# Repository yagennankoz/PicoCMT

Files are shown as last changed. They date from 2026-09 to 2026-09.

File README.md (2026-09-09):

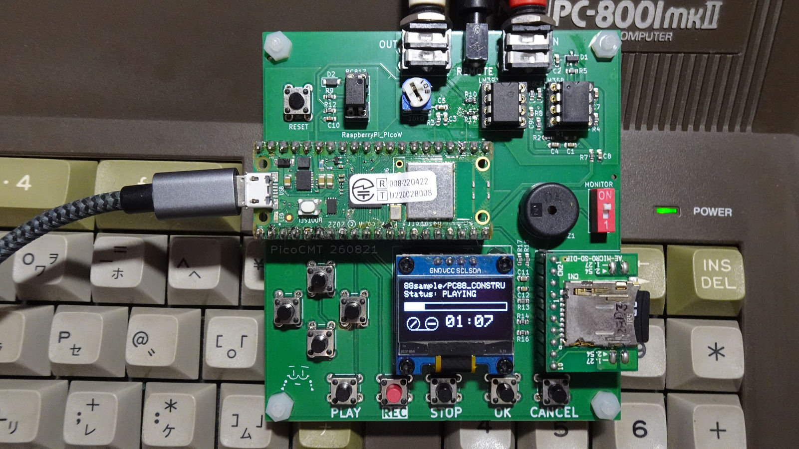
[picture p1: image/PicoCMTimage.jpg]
PicoCMT


# PicoCmt - 8bit PC用 CMT(カセット磁気テープ) エミュレータ

Raspberry Pi Pico W を使用した、8bitレトロPC向けのカセット磁気テープ（CMT）エミュレータです。
SDカードに保存されたテープイメージファイル（`.T88`, `.CMT`, `.CAS`）を実機へ音声信号としてロードしたり、実機からのセーブ音声を録音してデジタルファイルに変換・保存することができます。

## 主な機能
* **ファイルからの再生 (LOAD)**
  * 対応フォーマット: `.T88`, `.CMT`, `.CAS`)
  * ファイル内のデータをFSK音声信号に変換し、PCへ出力します。
  * 無音区間（ブランク）のスキップや頭出しシークが可能です。(T88)
* **実機からの録音・変換 (SAVE)**
  * PCからの出力音声を録音し、自動的にデジタル形式（`.T88`, `.CMT`, `.CAS`）に変換してSDカードに保存します。
  * 新規録音だけでなく、既存ファイルへの追記録音（アペンド）にも対応しています。
* **Wi-Fi / FTPサーバー機能**
  * Pico W のWi-Fi機能を利用し、内蔵のFTPサーバーを起動できます。
  * SDカードを抜き差しすることなく、PCやスマホからネットワーク経由でファイルの追加・削除が可能です。
  * 設定したWi-Fiパスワード等は独自の暗号化処理を経てEEPROMに安全に保存されます。

---

## 必要なハードウェア

基板のガーバーデータは`hardware/JLCPCB`を参照してください。JLCPCB等に発注することでプリント基板の生産が可能です。
主要な部品構成は以下の通りです。詳細な部品リストや定数は `hardware/parts.md` を参照してください。

* **マイコンボード:** Raspberry Pi Pico W
* **ディスプレイ:** 0.96インチ OLEDディスプレイ (SSD1306 / I2C接続)
* **ストレージ:** MicroSDカードモジュール (SPI接続)
* **アナログ回路:** 
  * オペアンプ `MCP6022` (信号増幅・波形整形用)
  * コンパレータ `LM393` (録音パルス検出用)
  * フォトカプラ `PC817` (REMOTE端子制御用)
* **インターフェース:**
  * タクトスイッチ ×10 (操作用)
  * 3.5mm モノラルジャック ×2 (LOAD用, SAVE用)
  * 2.5mm モノラルジャック ×1 (REMOTE制御用)
  * 圧電ブザー (モニタースピーカー用)

---

## 開発環境とビルド手順

本プロジェクトは **PlatformIO** を使用して開発されています。Arduinoコアには `earlephilhower` 版の Raspberry Pi PicoW/RP2040 コアを使用します。

### 1. インストール
1. リリースに配置されているファームウェアファイル`PicoCMT*.uf2`をダウンロードします。
2. PCとRaspberryPi PicoWをUSB接続します。
3. RaspberryPi PicoWの`BOOTSEL`ボタンを押しながら、PicoCMT基板上のRESETボタンを押下します。
4. PC上でRaspberryPi PicoWのフォルダが開かれますので、そこに`PicoCMT*.uf2'をコピーします。
5. RaspberryPi PicoWが自動で再起動され、PicoCMTが起動します。

### 2. 開発環境の準備
以下はソースコードからビルドする際の手順です。通常は不要です。
1. [Visual Studio Code (VSCode)](https://code.visualstudio.com/) をインストールします。
2. VSCodeの拡張機能から **PlatformIO IDE** をインストールします。
3. リポジトリをクローンしてください。

### 3. PIOファイルのコンパイルについて
PicoのPIO（アセンブリ）コードは、ビルド前に自動的にC/C++のヘッダファイルに変換される仕組みになっています。
`platformio.ini` 内の `extra_scripts = pre:scripts/generate_pio_headers.py` により、ビルド時に自動で `pio/` フォルダ内のファイルが処理され、`include/generated/` ディレクトリにヘッダファイルが出力されます。手動で実行する必要はありません。

### 4. ビルド
1. VSCodeで `PicoCmt` フォルダを開きます。
2. 初回起動時、PlatformIOが自動的に必要なツールチェーンとライブラリ（Adafruit GFX, SSD1306等）をダウンロードします。
3. 画面下のPlatformIOツールバーから **[✓] Build** をクリックしてビルドを実行します。

---

## 使い方・操作方法

操作方法については、付属の **操作マニュアル** を参照してください。
基本的なUI操作、再生（LOAD）・録音（SAVE）の手順、ボーレートの変更方法、Wi-Fi/FTP設定方法について記載されています。

---

## 注意事項・免責事項

* 本デバイスの接続や使用により発生したいかなる損害（レトロPC本体の故障、データの消失など）についても、開発者は責任を負いません。自己責任でご使用ください。
* Wi-Fi設定を保存する際に入力する「4桁のPINコード」は、設定情報を復号するために必要です。忘れるとWi-Fiに接続できなくなり、設定の初期化（クリア）が必要になります。

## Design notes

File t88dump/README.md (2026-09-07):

# T88/CMT フォーマット アナライザー & バイナリダンプ

PC-8801などのレトロPCで利用されるカセットテープイメージファイル（`.t88` および `.cmt`）の構造解析と、バイナリダンプを行うためのGUIツールです。
Pythonの標準ライブラリ（Tkinter）のみで実装されており、外部依存パッケージなしで軽量に動作します。

## ✨ 主な機能 (Features)

- **T88フォーマットの構造解析**
  - T88ファイル内の構造タグ（Blank, Data, Space, Mark 等）をパースし、Treeviewで一覧表示。
  - 再生時間（Ticks / ミリ秒）やデータサイズ、ボーレート（600/1200bps）を自動計算して表示。
- **CMTフォーマット対応**
  - 構造タグを持たない純粋なベタデータ（CMT）のフルダンプと解析に対応。
- **インタラクティブなバイナリダンプ**
  - 全体ダンプまたはタグ単体のHex＆ASCIIダンプを表示。
  - ダンプ画面の任意のバイトをクリックすると、クリック位置の絶対オフセット値、2進数ビット表現、所属するタグ情報などが下部のステータス解析ペインに表示されます。
- **ハイライト連動機能**
  - リストからタグを選択すると、全体ダンプ上でそのタグが占有しているバイナリ領域が黄色くハイライトされます。

## 💻 動作環境 (Requirements)

- Python 3.6 以上
- Tkinter が有効なPython環境（Windows版Pythonには標準で付属。Linux等の一部環境では別途 `python3-tk` などのインストールが必要な場合があります）

## 🚀 インストール手順 (Installation)

安全に実行するために、Pythonの仮想環境（venv）を構築して実行することを推奨します。

### 1. 仮想環境 (venv) の作成と有効化

**Windows の場合 (コマンドプロンプト / PowerShell):**
```cmd
python -m venv venv
venv\Scripts\activate
```

**macOS / Linux の場合:**
```bash
python3 -m venv venv
source venv/bin/activate
```
*(※ 環境が有効化されると、プロンプトの先頭に `(venv)` が表示されます)*

### 2. アプリケーションの起動
本ツールは外部ライブラリ（`requirements.txt` 等による `pip install`）を必要としません。仮想環境が有効な状態で、以下のコマンドを実行するだけで起動します。

**Windows の場合:**
```cmd
python main.py
```

**macOS / Linux の場合:**
```bash
python3 main.py
```
*(※ ファイル名が `main.py` ではない場合は、実行するファイル名に読み替えてください)*

## 📁 ファイル構成

- `main.py`
  - アプリケーションのエントリーポイント。メインGUI（T88GuiDumper）の定義およびウィジェットの配置を行います。
- `t88_widgets.py`
  - 16進数ダンプ表示、ピンポイントでのバイトハイライト機能、クリック座標からのオフセット計算機能を持つカスタムテキストウィジェットクラス（`DumpTextArea`）を定義しています。
- `t88_parser.py`
  - T88 / CMTファイルの読み込み、バイナリパース、タグ抽出、メタデータの計算などを行うデータ処理ロジッククラス（`TapeImageParser`）を定義しています。

## 📖 使い方 (Usage)

1. 画面左上の **「ファイルを開く」** ボタンをクリックし、解析したい `.t88` または `.cmt` ファイルを選択します。
2. **T88ファイル** の場合：
   - 「T88 構造解析ビュー」タブが開き、左側にタグ一覧が表示されます。
   - タグを選択すると、右側にそのタグのデータ部のみがダンプされ、下部ペインに詳細（Ticks、ボーレート等）が表示されます。
3. **CMTファイル** の場合：
   - タグが存在しないため「ファイル全体ダンプ」タブが自動的に開きます。
4. **ダンプ画面のクリック**：
   - Hexダンプ内の任意のバイトをクリックすると、その1バイトの詳細情報（2進数など）と、所属するタグブロックの情報が下部に表示されます。

## 🚪 仮想環境の終了
作業が終わったら、以下のコマンドで仮想環境を終了できます。
```bash
deactivate
```

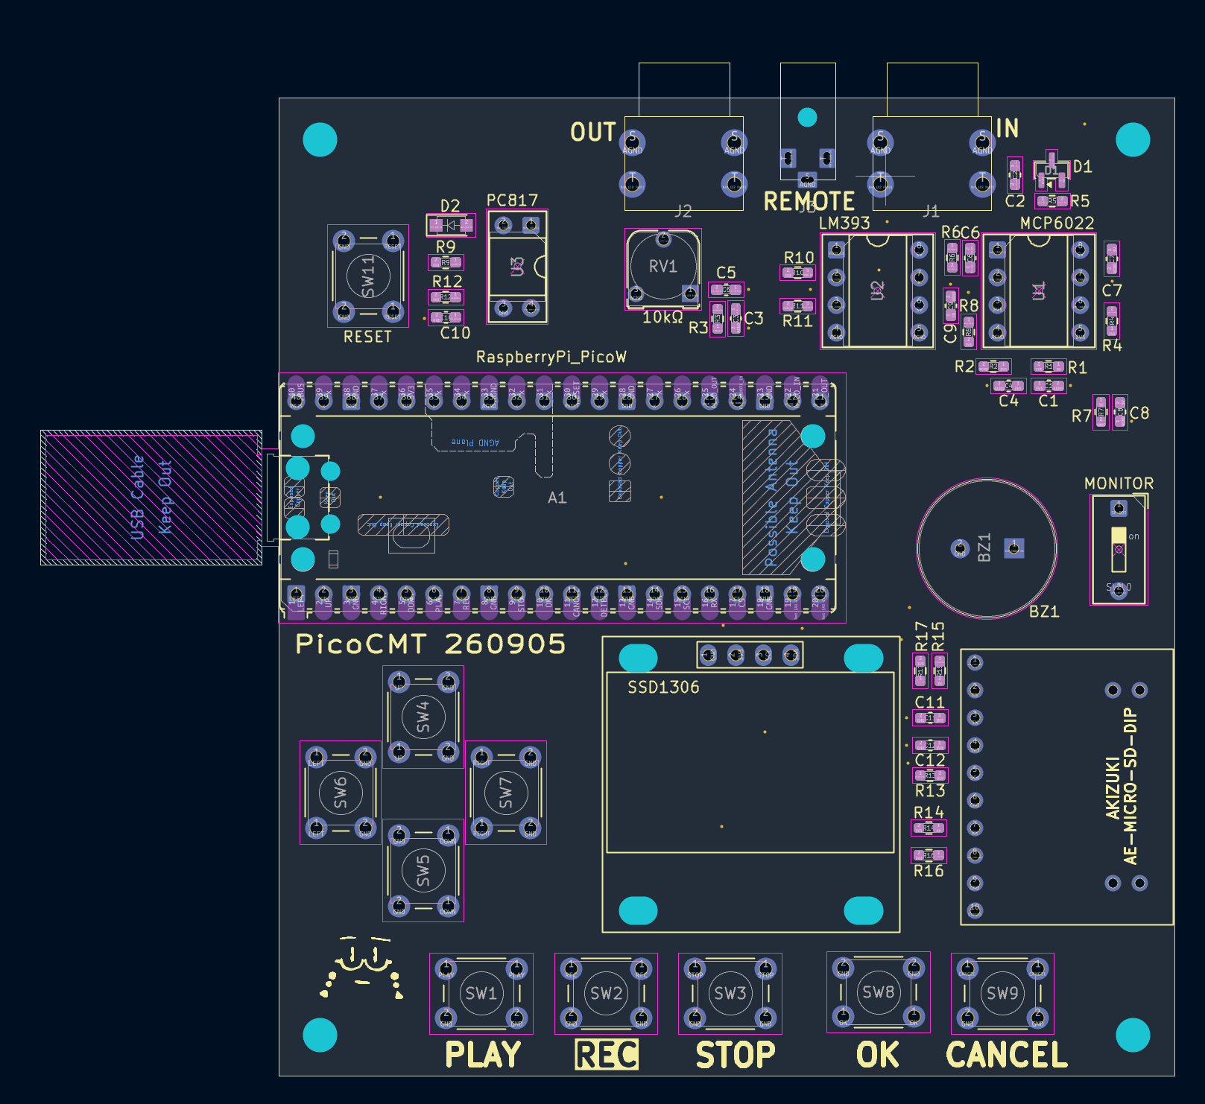
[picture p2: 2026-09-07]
image/board_img.png

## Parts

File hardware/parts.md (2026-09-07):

## カテゴリ別 部品リスト
実装や部品手配の際にご活用いただけるよう、種類別に分類しました。
抵抗とコンデンサのフットプリントは、表面実装の**1608サイズ (1.6mm×0.8mm)**の手はんだ（HandSolder）用パッド指定になっています。

### マイコン・モジュール類
* **RaspberryPi Pico W** ×1 (A1)
* **AE-MICRO-SD-DIP** (秋月電子MicroSDモジュール) ×1 (Brd1)
* **SSD1306** (128x64 OLEDディスプレイ) ×1 (Brd2)

### IC・半導体
* **MCP6022** (オペアンプ DIP-8) ×1 (U1)
* **LM393** (コンパレータ DIP-8) ×1 (U2)
* **PC817** (フォトカプラ DIP-4) ×1 (U3)
* **BAT54S** (ショットキーダイオード SOT-23) ×1 (D1)
* **1N4148** (スイッチングダイオード SOD-123W) ×1 (D2)

### 抵抗器 (0603 (1608M) SMD)
* **10Ω** ×1 (R7)
* **33Ω** ×2 (R13, R15)
* **470Ω** ×1 (R9)
* **1kΩ** ×1 (R3)
* **3.3kΩ** ×1 (R10)
* **4.7kΩ** ×1 (R12)
* **10kΩ** ×6 (R1, R2, R8, R14, R16, R17)
* **22kΩ** ×1 (R5)
* **100kΩ** ×2 (R4, R11)
* **1MΩ** ×1 (R6)

### 半固定抵抗 (ポテンショメータ)
* **10kΩ** 縦型(RM-065) ×1 (RV1)

### コンデンサ (0603 (1608M) SMD)
* **22pF** ×1 (C6)
* **22nF** ×1 (C3)
* **0.1uF** ×5 (C1, C7, C9, C10, C12)
* **1uF** ×2 (C2, C5)
* **10uF** ×3 (C4, C8, C11)

### スイッチ類
* **タクトスイッチ 6mm (H=4.3mm)** ×10 
  *(SW1〜SW9, SW11 / PLAY, REC, STOP, UP, DOWN, LEFT, RIGHT, OK, CANCEL, RESET)*
* **スライドスイッチ (SPST ディップスイッチ)** ×1 (SW10)

### コネクタ・その他
* **3.5mm モノラルジャック** RS PRO 3.5mmジャック/PCBマウント(913-1011) ×2 (J1 / SAVE, J2 / LOAD)
* **2.5mm モノラルジャック** RS PRO 2.5mmジャック/PCBマウント(913-1005) ×1 (J3 / REMOTE)
* **PS1240P02BT** (圧電ブザー スルーホール PS1240P02BT) ×1 (BZ1)

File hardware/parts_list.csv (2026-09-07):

ID | 指定子 | フットプリント | 数量 | 名称 | 供給業者、参考資料
1 | A1 | RaspberryPi_Pico_Common_Unspecified | 1 | RaspberryPi_Pico
2 | Brd1 | AE-MICRO-SD-DIP | 1 | ~
3 | Brd2 | 128x64OLED | 1 | SSD1306
4 | BZ1 | Piezo_Transducer_THT_PS1240P02BT | 1 | PS1240P02BT
5 | C1, C7, C9, C10, C12 | C_0603_1608Metric_Pad1.08x0.95mm_HandSolder | 5 | 0.1uF
6 | C2, C5 | C_0603_1608Metric_Pad1.08x0.95mm_HandSolder | 2 | 1uF
7 | C3 | C_0603_1608Metric_Pad1.08x0.95mm_HandSolder | 1 | 22nF
8 | C4, C8, C11 | C_0603_1608Metric_Pad1.08x0.95mm_HandSolder | 3 | 10uF
9 | C6 | C_0603_1608Metric_Pad1.08x0.95mm_HandSolder | 1 | 22pF
10 | D1 | SOT-23 | 1 | BAT54S
11 | D2 | Nexperia_CFP3_SOD-123W | 1 | 1N4148
12 | J1 | 3.5mm Jack MONO TS | 1 | PC_SAVE
13 | J2 | 3.5mm Jack MONO TS | 1 | PC_LOAD
14 | J3 | 2.5mm Jack MONO TS | 1 | PC_REMOTE
15 | R1, R2, R8, R14, R16, R17 | R_0603_1608Metric_Pad0.98x0.95mm_HandSolder | 6 | 10kΩ
16 | R3 | R_0603_1608Metric_Pad0.98x0.95mm_HandSolder | 1 | 1kΩ
17 | R4 | R_0603_1608Metric_Pad0.98x0.95mm_HandSolder | 1 | 100kΩ
18 | R5 | R_0603_1608Metric_Pad0.98x0.95mm_HandSolder | 1 | 22kΩ
19 | R6 | R_0603_1608Metric_Pad0.98x0.95mm_HandSolder | 1 | 1MΩ
20 | R7 | R_0603_1608Metric_Pad0.98x0.95mm_HandSolder | 1 | 10Ω
21 | R9 | R_0603_1608Metric_Pad0.98x0.95mm_HandSolder | 1 | 470Ω
22 | R10 | R_0603_1608Metric_Pad0.98x0.95mm_HandSolder | 1 | 3.3kΩ
23 | R11 | R_0603_1608Metric_Pad0.98x0.95mm_HandSolder | 1 | 100kΩ
24 | R12 | R_0603_1608Metric_Pad0.98x0.95mm_HandSolder | 1 | 4.7kΩ
25 | R13, R15 | R_0603_1608Metric_Pad0.98x0.95mm_HandSolder | 2 | 33Ω
26 | REF**, REF**, REF**, REF** | DHM3 | 4 | DHM3
27 | REF**, REF**, REF**, REF** | DHM2 | 4 | DHM2
28 | RV1 | Potentiometer_Runtron_RM-065_Vertical | 1 | 10kΩ
29 | SW1 | SW_PUSH_6mm_H4.3mm | 1 | PLAY
30 | SW2 | SW_PUSH_6mm_H4.3mm | 1 | REC
31 | SW3 | SW_PUSH_6mm_H4.3mm | 1 | STOP
32 | SW4 | SW_PUSH_6mm_H4.3mm | 1 | UP
33 | SW5 | SW_PUSH_6mm_H4.3mm | 1 | DOWN
34 | SW6 | SW_PUSH_6mm_H4.3mm | 1 | LEFT
35 | SW7 | SW_PUSH_6mm_H4.3mm | 1 | RIGHT
36 | SW8 | SW_PUSH_6mm_H4.3mm | 1 | OK
37 | SW9 | SW_PUSH_6mm_H4.3mm | 1 | CANCEL
38 | SW10 | SW_DIP_SPSTx01_Slide_9.78x4.72mm_W7.62mm_P2.54mm | 1 | SW_SPST
39 | SW11 | SW_PUSH_6mm_H4.3mm | 1 | RESET
40 | U1 | DIP-8_W7.62mm_Socket | 1 | MCP6022
41 | U2 | DIP-8_W7.62mm_Socket | 1 | LM393
42 | U3 | DIP-4_W7.62mm_Socket | 1 | PC817

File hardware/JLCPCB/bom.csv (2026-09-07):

Designator | Footprint | Quantity | Value | LCSC Part #
A1 | RaspberryPi_Pico_Common_Unspecified | 1 | RaspberryPi_Pico
BRD1 | AE-MICRO-SD-DIP | 1 | ~
BRD2 | 128x64OLED | 1 | SSD1306
BZ1 | Piezo_Transducer_THT_PS1240P02BT | 1 | PS1240P02BT | PS1240P02BT
C1, C10, C12, C7, C9 | 0603 | 5 | 0.1uF | C14663
C11, C4, C8 | 0603 | 3 | 10uF | C19702
C2, C5 | 0603 | 2 | 1uF | C15849
C3 | 0603 | 1 | 22nF | C21122
C6 | 0603 | 1 | 22pF | C1653
D1 | SOT-23 | 1 | BAT54S | C83935
D2 | Nexperia_CFP3_SOD-123W | 1 | 1N4148 | C81598
J1 | 3.5mm Jack MONO TS | 1 | PC_SAVE
J2 | 3.5mm Jack MONO TS | 1 | PC_LOAD
J3 | 2.5mm Jack MONO TS | 1 | PC_REMOTE
R1, R14, R16, R17, R2, R8 | 0603 | 6 | 10kΩ | C25804
R10 | 0603 | 1 | 3.3kΩ | C22978
R11, R4 | 0603 | 2 | 100kΩ | C25803
R12 | 0603 | 1 | 4.7kΩ | C23162
R13, R15 | 0603 | 2 | 33Ω | C23140
R3 | 0603 | 1 | 1kΩ | C21190
R5 | 0603 | 1 | 22kΩ | C31850
R6 | 0603 | 1 | 1MΩ | C22935
R7 | 0603 | 1 | 10Ω | C22859
R9 | 0603 | 1 | 470Ω | C23179
RV1 | Potentiometer_Runtron_RM-065_Vertical | 1 | 10kΩ
SW1 | SW_PUSH_6mm_H4.3mm | 1 | PLAY
SW10 | SW_DIP_SPSTx01_Slide_9.78x4.72mm_W7.62mm_P2.54mm | 1 | SW_SPST
SW11 | SW_PUSH_6mm_H4.3mm | 1 | RESET
SW2 | SW_PUSH_6mm_H4.3mm | 1 | REC
SW3 | SW_PUSH_6mm_H4.3mm | 1 | STOP
SW4 | SW_PUSH_6mm_H4.3mm | 1 | UP
SW5 | SW_PUSH_6mm_H4.3mm | 1 | DOWN
SW6 | SW_PUSH_6mm_H4.3mm | 1 | LEFT
SW7 | SW_PUSH_6mm_H4.3mm | 1 | RIGHT
SW8 | SW_PUSH_6mm_H4.3mm | 1 | OK
SW9 | SW_PUSH_6mm_H4.3mm | 1 | CANCEL
U1 | DIP-8_W7.62mm_Socket | 1 | MCP6022
U2 | DIP-8_W7.62mm_Socket | 1 | LM393
U3 | DIP-4_W7.62mm_Socket | 1 | PC817

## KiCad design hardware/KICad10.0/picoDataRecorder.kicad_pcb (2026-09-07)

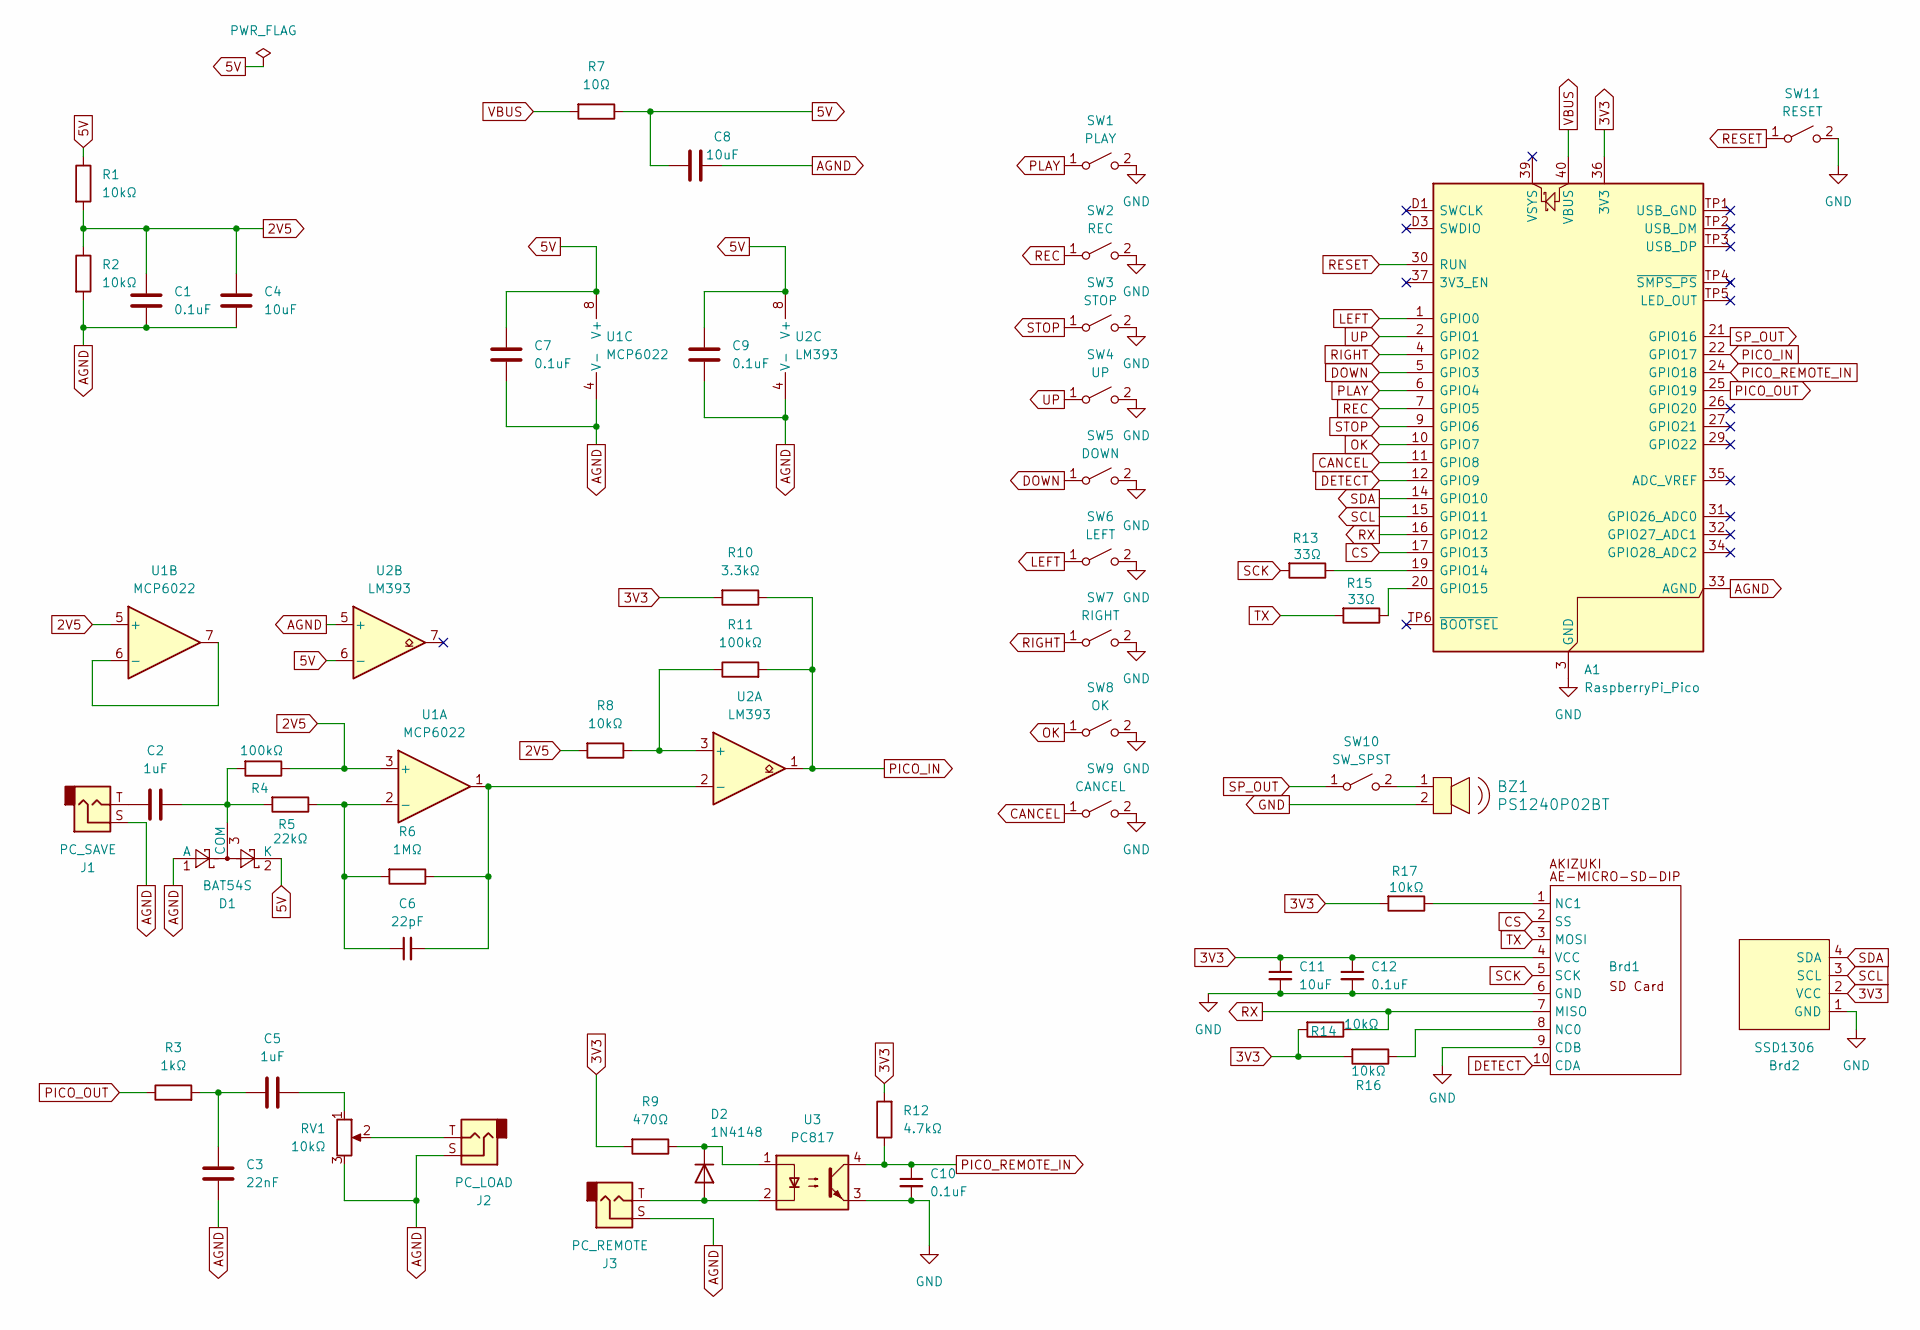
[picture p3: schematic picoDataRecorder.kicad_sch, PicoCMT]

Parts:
A1: RaspberryPi_Pico; RaspberryPi_Pico_Common_Unspecified
BZ1: PS1240P02BT; Piezo_Transducer_THT_PS1240P02BT; MPN PS1240P02BT; Digi-Key_PN 445-2525-1-ND
Brd1: AE-MICRO-SD-DIP
Brd2: SSD1306; 128x64OLED
C1, C7, C9, C10, C12: 0.1uF; C_0603_1608Metric_Pad1.08x0.95mm_HandSolder; LCSC C14663
C2, C5: 1uF; C_0603_1608Metric_Pad1.08x0.95mm_HandSolder; LCSC C15849
C3: 22nF; C_0603_1608Metric_Pad1.08x0.95mm_HandSolder; LCSC C21122
C4, C8, C11: 10uF; C_0603_1608Metric_Pad1.08x0.95mm_HandSolder; LCSC C19702
C6: 22pF; C_0603_1608Metric_Pad1.08x0.95mm_HandSolder; LCSC C1653
D1: BAT54S; SOT-23; LCSC C83935
D2: 1N4148; Nexperia_CFP3_SOD-123W; LCSC C81598
J1: PC_SAVE; 3.5mm Jack MONO TS
J2: PC_LOAD; 3.5mm Jack MONO TS
J3: PC_REMOTE; 2.5mm Jack MONO TS
R1, R2, R8, R14, R16, R17: 10kΩ; R_0603_1608Metric_Pad0.98x0.95mm_HandSolder; LCSC C25804
R3: 1kΩ; R_0603_1608Metric_Pad0.98x0.95mm_HandSolder; LCSC C21190
R4, R11: 100kΩ; R_0603_1608Metric_Pad0.98x0.95mm_HandSolder; LCSC C25803
R5: 22kΩ; R_0603_1608Metric_Pad0.98x0.95mm_HandSolder; LCSC C31850
R6: 1MΩ; R_0603_1608Metric_Pad0.98x0.95mm_HandSolder; LCSC C22935
R7: 10Ω; R_0603_1608Metric_Pad0.98x0.95mm_HandSolder; LCSC C22859
R9: 470Ω; R_0603_1608Metric_Pad0.98x0.95mm_HandSolder; LCSC C23179
R10: 3.3kΩ; R_0603_1608Metric_Pad0.98x0.95mm_HandSolder; LCSC C22978
R12: 4.7kΩ; R_0603_1608Metric_Pad0.98x0.95mm_HandSolder; LCSC C23162
R13, R15: 33Ω; R_0603_1608Metric_Pad0.98x0.95mm_HandSolder; LCSC C23140
RV1: 10kΩ; Potentiometer_Runtron_RM-065_Vertical
SW1: PLAY; SW_PUSH_6mm_H4.3mm
SW2: REC; SW_PUSH_6mm_H4.3mm
SW3: STOP; SW_PUSH_6mm_H4.3mm
SW4: UP; SW_PUSH_6mm_H4.3mm
SW5: DOWN; SW_PUSH_6mm_H4.3mm
SW6: LEFT; SW_PUSH_6mm_H4.3mm
SW7: RIGHT; SW_PUSH_6mm_H4.3mm
SW8: OK; SW_PUSH_6mm_H4.3mm
SW9: CANCEL; SW_PUSH_6mm_H4.3mm
SW10: SW_SPST; SW_DIP_SPSTx01_Slide_9.78x4.72mm_W7.62mm_P2.54mm
SW11: RESET; SW_PUSH_6mm_H4.3mm
U1: MCP6022; DIP-8_W7.62mm_Socket
U2: LM393; DIP-8_W7.62mm_Socket
U3: PC817; DIP-4_W7.62mm_Socket

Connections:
2V5: C1.1, C4.1, R1.2, R2.1, R4.1, R8.2, U1.3 (+), U1.5 (+)
3V3: A1.36 (3V3), Brd1.4 (VCC), Brd2.2 (VCC), C11.1, C12.1, R9.2, R10.2, R12.2, R14.2, R16.2, R17.2
5V: C7.1, C8.2, C9.1, D1.2 (K), R1.1, R7.1, U1.8 (V+), U2.6 (-), U2.8 (V+)
AGND: A1.33 (AGND), C1.2, C3.2, C4.2, C7.2, C8.1, C9.2, D1.1 (A), J1.S, J2.S, J3.S, R2.2, RV1.3, U1.4 (V-), U2.4 (V-), U2.5 (+)
CANCEL: A1.11 (GPIO8), SW9.1 (A)
CS: A1.17 (GPIO13), Brd1.2 (SS)
DETECT: A1.12 (GPIO9), Brd1.10 (CDA)
DOWN: A1.5 (GPIO3), SW5.1 (A)
GND: A1.3 (GND), A1.8 (GND), A1.13 (GND), A1.18 (GND), A1.23 (GND), A1.28 (GND), A1.38 (GND), A1.D2 (GND), BZ1.2, Brd1.6 (GND), Brd1.9 (CDB), Brd2.1 (GND), C10.2, C11.2, C12.2, SW1.2 (B), SW2.2 (B), SW3.2 (B), SW4.2 (B), SW5.2 (B), SW6.2 (B), SW7.2 (B), SW8.2 (B), SW9.2 (B), SW11.2 (B), U3.3
LEFT: A1.1 (GPIO0), SW6.1 (A)
unnamed: A1.19 (GPIO14), R13.1
unnamed: A1.20 (GPIO15), R15.1
unnamed: Brd1.8 (NC0), R16.1
unnamed: Brd1.1 (NC1), R17.1
unnamed: C2.2, J1.T
unnamed: C3.1, C5.1, R3.2
unnamed: C5.2, RV1.1
unnamed: C2.1, D1.3 (COM), R4.2, R5.2
unnamed: D2.2 (A), J3.T, U3.2
unnamed: D2.1 (K), R9.1, U3.1
unnamed: J2.T, RV1.2
unnamed: BZ1.1, SW10.2 (B)
unnamed: C6.1, R5.1, R6.2, U1.2 (-)
unnamed: U1.6 (-), U1.7
unnamed: R8.1, R11.1, U2.3 (+)
unnamed: C6.2, R6.1, U1.1, U2.2 (-)
OK: A1.10 (GPIO7), SW8.1 (A)
PICO_IN: A1.22 (GPIO17), R10.1, R11.2, U2.1
PICO_OUT: A1.25 (GPIO19), R3.1
PICO_REMOTE_IN: A1.24 (GPIO18), C10.1, R12.1, U3.4
PLAY: A1.6 (GPIO4), SW1.1 (A)
REC: A1.7 (GPIO5), SW2.1 (A)
RESET: A1.30 (RUN), SW11.1 (A)
RIGHT: A1.4 (GPIO2), SW7.1 (A)
RX: A1.16 (GPIO12), Brd1.7 (MISO), R14.1
SCK: Brd1.5 (SCK), R13.2
SCL: A1.15 (GPIO11), Brd2.3 (SCL)
SDA: A1.14 (GPIO10), Brd2.4 (SDA)
SP_OUT: A1.21 (GPIO16), SW10.1 (A)
STOP: A1.9 (GPIO6), SW3.1 (A)
TX: Brd1.3 (MOSI), R15.2
UP: A1.2 (GPIO1), SW4.1 (A)
VBUS: A1.40 (VBUS), R7.2

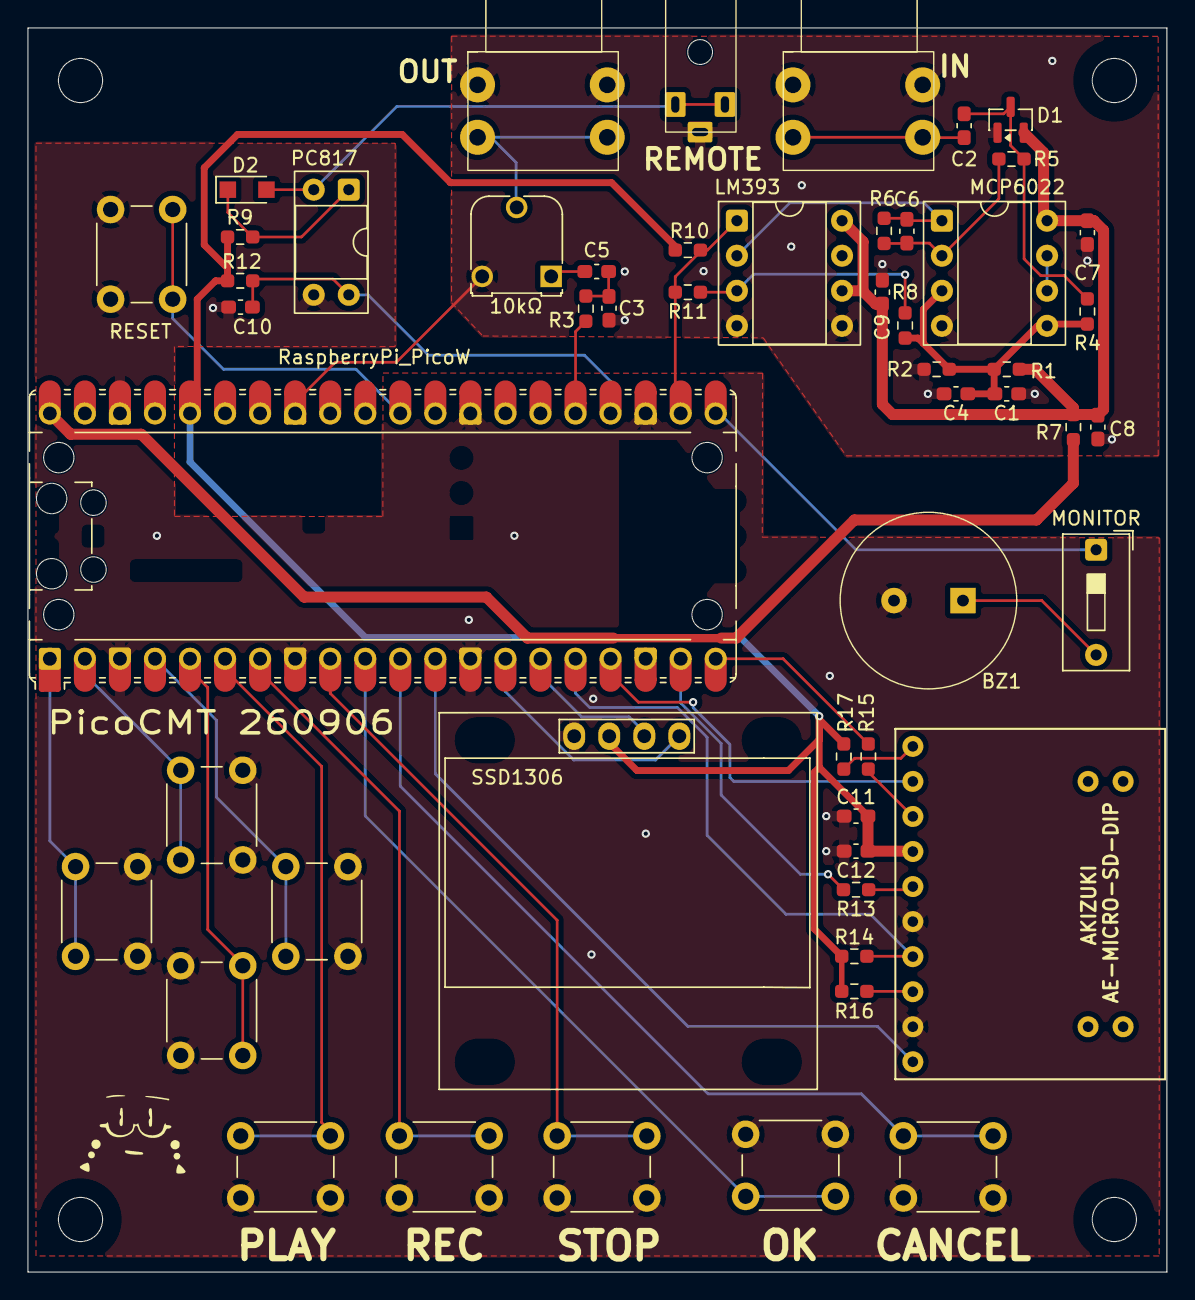
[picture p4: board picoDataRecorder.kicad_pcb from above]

Board: 2 copper layers, 82.6 x 90.2 mm, 53 parts (0 on the bottom side), 43 nets.

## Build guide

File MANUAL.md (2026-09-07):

# PicoCmt 操作マニュアル

本デバイスは、Raspberry Pi Pico Wを使用した8bitレトロPC向けのCMT（カセット磁気テープ）エミュレータです。SDカード内のイメージファイル（.T88, .CMT, .CASなど）を音声として再生（ロード）したり、実機からの音声を録音（セーブ）してイメージファイルに変換しSDに保存することができます。また、WiFi経由でのFTPファイル転送にも対応しています。

## 1. ボタン構成と基本操作

本体には9つの操作ボタンがあります。

*   **[UP] / [DOWN]**: カーソルの上下移動、文字・数字の変更
*   **[LEFT] / [RIGHT]**: 階層の移動、ボーレート変更、頭出し（シーク）、カーソルの左右移動
*   **[OK]**: 決定、フォルダを開く、再生・録音の開始/一時停止
*   **[CANCEL]**: キャンセル、上の階層へ戻る
*   **[PLAY]**: 再生の開始/一時停止
*   **[REC]**: 録音の開始、WiFi設定時の保存アクション
*   **[STOP]**: 停止、アイドル画面への復帰、設定メニューへの遷移（長押しまたは連続押し）

---

## 2. ファイルブラウザ（アイドル画面）

SDカード挿入時、最初に表示される画面です。SDカード内のファイルやフォルダを選択します。

*   **移動**: **[UP] / [DOWN]** ボタンでファイルを選択します。
*   **フォルダを開く**: フォルダを選択して **[OK]** または **[RIGHT]** を押します。
*   **上の階層に戻る**: **[CANCEL]** または **[LEFT]** を押します。

### ボーレートの変更機能
ファイルリスト上で拡張子が `.CMT` または `.CAS` のファイルを選択すると、画面右にボーレート設定UIが表示されます。
*   ファイルを選択した状態で **[LEFT] / [RIGHT]** を押すとボーレートを切り替えられます。
    *   **CMTファイル**: `600` または `1200`
    *   **CASファイル**: `1200` または `2400`

---

## 3. テープの再生（PCへのロード）

PCへプログラムをロードする際の操作です。

1.  ファイルブラウザで再生したいファイルを選択し、**[OK]** または **[PLAY]** を押します。
2.  **「REC STANDBY」**(再生待機) 画面になります。
3.  PC側でロードコマンド（`LOAD` や `CLOAD` など）を実行します。
4.  本機の **[OK]** または **[PLAY]** を押すと再生（PLAYING）が開始され、テープアニメーションが動きます。
5.  再生中に **[PLAY]** を押すと一時停止（PAUSED）します。
6.  終了・中断する場合は **[STOP]** を押すとファイルブラウザに戻ります。

### 無音区間のスキップ（頭出し機能）
再生待機中、または再生中に **[LEFT] / [RIGHT]** ボタンを押すと、テープの無音区間（ブランク）を検知して前後のデータブロックへスキップ（シーク）することができます。

---

## 4. テープへの録音（PCからのセーブ）

PCから出力されるピーガー音を録音し、デジタルファイルに変換・保存します。

### 4-1. 新規録音
1.  ファイルブラウザ画面で、フォルダまたは録音非対応ファイルを選択した状態で **[REC]** を押します。
2.  自動的に `NEWRECxxx.T88`（※拡張子は設定による）というファイル名が割り当てられ、録音待機状態になります。
3.  本機の **[OK]** を押すと録音が開始されます。PC側でセーブコマンドを実行してください。
4.  保存が終わったら **[STOP]** を押します。
5.  自動的に「Converting...」画面が表示され、録音されたRAW音声データが指定のファイル形式に変換・保存されます。

### 4-2. 追記録音（アペンド）
1.  ファイルブラウザで既存の対応ファイル（`.T88`, `.CAS`）を選択し、**[REC]** を押します。
2.  録音メニューが表示されます。
    *   `Create New File` (新規作成)
    *   `Append to File` (選択したファイルに追記)
3.  **[UP] / [DOWN]** で選択し、**[OK]** を押して録音待機画面へ進みます。以降は新規録音と同じです。

*(※現在のバージョンでは RAWから T88 および CMT への変換がサポートされています)*

---

## 5. 設定メニュー（WiFi・録音フォーマット設定）

ファイルブラウザ画面で **[STOP]** を長押しすると、設定メニュー（SETTINGS）が開きます。

### 5-1. REC Format (録音フォーマットの変更)
メニューから `Rec Fmt` にカーソルを合わせ、**[LEFT] / [RIGHT]** を押すことで、新規録音時に作成されるファイルの形式を選択できます。
*   選択肢: `T88` / `CMT` / `CAS`

### 5-2. WiFi機能とFTPサーバー
Pico WのWiFi機能を利用して、SDカードを抜き差しすることなくFTP経由でファイルを転送できます。

#### WiFiの初期設定
1.  設定メニューの `WiFi Config` を選択し **[OK]** を押します。
2.  周囲のアクセスポイントをスキャンします。**[UP] / [DOWN]** で接続したいSSIDを選び、**[OK]** を押します。
3.  パスワード入力画面になります。**[UP] / [DOWN]** で文字を選択、**[RIGHT] / [LEFT]** で桁を移動し、完了したら **[REC]** を押します。
4.  **PINコード入力画面** になります。これはパスワードを暗号化して保存するための**4桁の暗証番号**です。任意の数字を設定し、**[OK]** で保存します。

#### WiFiへの接続
1.  設定メニューの `WiFi:` の項目を `ON` にします。
2.  PINコードの入力を求められるので、初期設定で決めた4桁の数字を入力して **[OK]** を押します。
3.  接続が成功すると、画面下部に `IPアドレス` とFTP接続用の `ID` / `PW` が表示されます。
4.  PCのFTPクライアントソフトに表示されたIP、ID、パスワードを入力して接続してください。

#### WiFi設定のリセット
設定メニューの `WiFi:` を **[LEFT] / [RIGHT]** ボタンで `CLEAR` に変更し、**[OK]** を押すと、保存されているSSIDとパスワード情報が安全に消去されます。

*(※注意: 再生中や録音中は処理落ちを防ぐため、WiFiおよびFTP機能は自動的に切断されます。)*

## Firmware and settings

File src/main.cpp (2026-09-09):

#include <Adafruit_GFX.h>
#include <Adafruit_SSD1306.h>
#include <Arduino.h>
#include <SD.h>
#include <SPI.h>
#include <Wire.h>

#include "cmt_cmt_converter.h"
#include "cmt_control.h"
#include "cmt_core1.h"
#include "cmt_globals.h"
#include "cmt_hw_config.h"
#include "cmt_network.h"
#include "cmt_pins.h"
#include "cmt_storage.h"
#include "cmt_storage_record.h"
#include "cmt_t88_converter.h"
#include "cmt_types.h"
#include "cmt_ui.h"
#include "cmt_ui_input.h"
#include "hardware/watchdog.h"
#include "pico/util/queue.h"

volatile SystemState current_state = STATE_IDLE;
RecMode selected_rec_mode = MODE_NEW;
RemoteState current_remote_state = REMOTE_OFF;
uint32_t remote_stable_time = 0;

volatile bool playback_permitted = false;
volatile bool recording_permitted = false;
bool manual_ok_override = false;
volatile bool playback_user_paused = false;

volatile bool recording_active = false;
volatile bool play_active = false;
volatile bool rec_paused = true;
volatile bool play_paused = true;

volatile bool playback_started = false;

FileItem file_list[MAX_FILES];
int total_items = 0;
int current_cursor = 0;
int scroll_offset = 0;
String current_path = "/";

queue_t cmt_data_queue;
queue_t cmt_play_queue;
int buffer_idx = 0;

File cmt_file;
int rec_menu_cursor = 0;
char target_filename[128];

ButtonTracker buttons[NUM_BUTTONS];
volatile bool btn_trigger_clicked[NUM_BUTTONS] = {false};
volatile bool btn_trigger_repeat[NUM_BUTTONS] = {false};

Adafruit_SSD1306 oled(128, 64, &Wire1, -1);

int pio_rec_sm = 0;
int pio_play_sm = 1;

bool oled_need_refresh = true;
bool sd_card_inserted = false;
bool sd_card_mounted = false;
static uint32_t last_idle_oled_refresh_ms = 0;
static uint32_t last_playback_oled_refresh_ms = 0;
static uint32_t stop_button_hold_start_ms = 0;

int cmt_selected_baud_rate = 1200;
int cas_selected_baud_rate = 1200;

static bool is_sd_inserted() {
    static uint32_t last_probe_ms = 0;
    static bool last_probe_result = false;
    uint32_t now = millis();

    if (now - last_probe_ms < 1000) {
        return last_probe_result;
    }
    last_probe_ms = now;

    if (sd_card_mounted) {
        File root = SD.open("/");
        if (root) {
            root.close();
            last_probe_result = true;
            return true;
        }
        last_probe_result = false;
        return false;
    } else {
        if (gpio_get(PICO_SPI_DETECT_PIN) == 0) {
            last_probe_result = true;
            return true;
        }
        SD.end();
        if (SD.begin(PICO_SD_CS_PIN, SD_SCK_MHZ(24), SPI1)) {
            SD.end();
            last_probe_result = true;
            return true;
        }
        last_probe_result = false;
        return false;
    }
}

static bool mount_sd_card() {
    SD.end();
    if (SD.begin(PICO_SD_CS_PIN, SD_SCK_MHZ(16), SPI1)) {
        sd_card_mounted = true;
        sd_card_inserted = true;
        if (!load_directory(current_path)) {
            SD.end();
            sd_card_mounted = false;
            sd_card_inserted = false;
            return false;
        }
        return true;
    }
    sd_card_mounted = false;
    return false;
}

static void refresh_directory_if_idle() {
    static uint32_t last_refresh_ms = 0;
    uint32_t now_ms = millis();

    if (current_state != STATE_IDLE || !sd_card_mounted) {
        return;
    }
    if ((now_ms - last_refresh_ms) < 2000) {
        return;
    }
    last_refresh_ms = now_ms;

    int prev_total = total_items;
    int prev_cursor = current_cursor;
    int prev_scroll = scroll_offset;

    char selected_name[MAX_NAME_LEN] = {0};
    bool selected_is_dir = false;
    bool has_selection = false;

    if (total_items > 0 && current_cursor >= 0 &&
        current_cursor < total_items) {
        snprintf(selected_name, sizeof(selected_name), "%s",
                 file_list[current_cursor].name);
        selected_is_dir = file_list[current_cursor].is_dir;
        has_selection = true;
    }

    if (!load_directory(current_path)) {
        SD.end();
        sd_card_mounted = false;
        sd_card_inserted = false;
        total_items = 0;
        current_cursor = 0;
        scroll_offset = 0;
        oled_need_refresh = true;
        return;
    }

    if (has_selection && total_items > 0) {
        int restored_idx = -1;
        for (int i = 0; i < total_items; i++) {
            if (file_list[i].is_dir == selected_is_dir &&
                strcmp(file_list[i].name, selected_name) == 0) {
                restored_idx = i;
                break;
            }
        }
        if (restored_idx >= 0) {
            current_cursor = restored_idx;
        } else if (prev_cursor < total_items) {
            current_cursor = (prev_cursor >= 0) ? prev_cursor : 0;
        } else {
            current_cursor = (total_items > 0) ? (total_items - 1) : 0;
        }
    }

    if (total_items <= 0) {
        current_cursor = 0;
        scroll_offset = 0;
    } else {
        if (current_cursor < 0) {
            current_cursor = 0;
        }
        if (current_cursor >= total_items) {
            current_cursor = total_items - 1;
        }

        scroll_offset = prev_scroll;
        if (current_cursor < scroll_offset) {
            scroll_offset = current_cursor;
        }
        if (current_cursor - scroll_offset >= 4) {
            scroll_offset = current_cursor - 3;
        }
        if (total_items > 4 && scroll_offset > total_items - 4) {
            scroll_offset = total_items - 4;
        }
        if (scroll_offset < 0) {
            scroll_offset = 0;
        }
    }

    if (total_items != prev_total || current_cursor != prev_cursor ||
        scroll_offset != prev_scroll) {
        oled_need_refresh = true;
    }
}

static void monitor_sd_card_hotplug() {
    uint32_t now = millis();
    static uint32_t last_check_ms = 0;

    if (now - last_check_ms < 500) {
        return;
    }
    last_check_ms = now;

    bool detect_pin_inserted = (gpio_get(PICO_SPI_DETECT_PIN) == 0);

    if (sd_card_mounted) {
        if (!detect_pin_inserted) {
            SD.end();
            sd_card_mounted = false;
            sd_card_inserted = false;
            recording_active = false;
            rec_paused = true;
            stop_playback_and_return_idle();

            current_state = STATE_IDLE;
            current_path = "/";
            total_items = 0;
            current_cursor = 0;
            scroll_offset = 0;
            reset_and_ignore_pressed_buttons();
            oled_need_refresh = true;
        }
    } else {
        if (detect_pin_inserted) {
            if (mount_sd_card()) {
                current_state = STATE_IDLE;
                reset_and_ignore_pressed_buttons();
                oled_need_refresh = true;
            }
        } else {
            static uint32_t last_probe_ms = 0;
            if (now - last_probe_ms > 2000) {
                last_probe_ms = now;
                if (mount_sd_card()) {
                    current_state = STATE_IDLE;
                    reset_and_ignore_pressed_buttons();
                    oled_need_refresh = true;
                }
            }
        }
    }
}

void setup() {
    Serial.begin(115200);
    unsigned long start = millis();
    while (!Serial && (millis() - start < 3000)) {
        delay(100);
    }
    Serial.println("\n--- CMT to T88 Converter Starting ---");

    init_ui_buttons();

    gpio_init(REMOTE_PIN);
    gpio_set_dir(REMOTE_PIN, GPIO_IN);
    gpio_pull_up(REMOTE_PIN);

    gpio_init(PICO_SPI_DETECT_PIN);
    gpio_set_dir(PICO_SPI_DETECT_PIN, GPIO_IN);
    gpio_pull_up(PICO_SPI_DETECT_PIN);

    init_cores_communication();
    watchdog_enable(4000, 0);

    Wire1.setSDA(PICO_I2C_SDA_PIN);
    Wire1.setSCL(PICO_I2C_SCL_PIN);
    Wire1.begin();

    if (!oled.begin(SSD1306_SWITCHCAPVCC, SCREEN_ADDRESS)) {
        while (1) {
            delay(100);
        }
    }

    init_wifi_and_settings();

    SPI1.setRX(PICO_SPI_MISO_PIN);
    SPI1.setTX(PICO_SPI_MOSI_PIN);
    SPI1.setSCK(PICO_SPI_CLK_PIN);
    SPI1.begin();
    pinMode(PICO_SD_CS_PIN, OUTPUT);
    digitalWrite(PICO_SD_CS_PIN, HIGH);

    mount_sd_card();

    oled.clearDisplay();
    oled.setTextSize(1);
    oled.setTextColor(SSD1306_WHITE);
    oled.setCursor(0, 0);
    oled.println("PicoCmt");
    oled.setCursor(0, 12);
    oled.println("WiFi: OFF");
    oled.display();
    oled_need_refresh = true;
}

void loop() {
    watchdog_update();
    uint32_t now_ms = millis();

    bool stop_pressed_raw = (gpio_get(BTN_STOP_PIN) == 0);
    if (stop_pressed_raw) {
        if (stop_button_hold_start_ms == 0) {
            stop_button_hold_start_ms = now_ms;
        } else if ((now_ms - stop_button_hold_start_ms) > 800) {
            if (current_state == STATE_PLAYING ||
                current_state == STATE_PLAY_STANDBY) {
                stop_playback_and_return_idle();
                reset_and_ignore_pressed_buttons();
                oled_need_refresh = true;
            }
            stop_button_hold_start_ms = now_ms;
        }
    } else {
        stop_button_hold_start_ms = 0;
    }

    handle_wifi_background_tasks();

    if (current_state == STATE_PLAY_STANDBY || current_state == STATE_PLAYING) {
        if ((now_ms - last_playback_oled_refresh_ms) >= 250) {
            last_playback_oled_refresh_ms = now_ms;
            oled_need_refresh = true;
        }
    } else {
        last_playback_oled_refresh_ms = 0;
    }

    static uint32_t last_rec_oled_refresh_ms = 0;
    if (current_state == STATE_RECORDING) {
        if ((now_ms - last_rec_oled_refresh_ms) >= 250) {
            last_rec_oled_refresh_ms = now_ms;
            oled_need_refresh = true;
        }
    } else {
        last_rec_oled_refresh_ms = 0;
    }

    if (current_state == STATE_IDLE && sd_card_mounted) {
        if ((now_ms - last_idle_oled_refresh_ms) >= 180) {
            last_idle_oled_refresh_ms = now_ms;
            oled_need_refresh = true;
        }
    } else {
        last_idle_oled_refresh_ms = 0;
    }

    scan_ui_buttons();
    scan_remote_hardware();
    monitor_sd_card_hotplug();
    refresh_directory_if_idle();

    switch (current_state) {
        case STATE_IDLE:
            if (sd_card_mounted) {
                handle_file_browser_input();
            }
            break;
        case STATE_REC_MENU:
            handle_rec_menu_input();
            break;
        case STATE_WIFI_MENU:
            handle_wifi_menu_input();
            break;
        case STATE_WIFI_CONFIG:
            handle_wifi_config_input();
            break;
        case STATE_WIFI_PIN_CONNECT:
            handle_wifi_pin_connect_input();
            break;
        case STATE_WIFI_SAVE_RESULT:
            if ((int32_t)(now_ms - wifi_save_result_until_ms) >= 0) {
                wifi_menu_cursor = wifi_settings_saved ? 0 : 1;
                current_state = STATE_WIFI_MENU;
                reset_and_ignore_pressed_buttons();
                oled_need_refresh = true;
            }
            break;
        case STATE_WIFI_CONNECT_ERROR:
            handle_wifi_connect_error_input();
            break;
        case STATE_REC_STANDBY:
        case STATE_PLAY_STANDBY:
            handle_ui_buttons_in_standby();
            break;
        case STATE_RECORDING:
            handle_raw_recording_stream();

            if (!recording_active || btn_trigger_clicked[IDX_STOP]) {
                if (btn_trigger_clicked[IDX_STOP]) {
                    btn_trigger_clicked[IDX_STOP] = false;
                    stop_raw_recording_and_finalize();
                }

                current_state = STATE_IDLE;
                reset_and_ignore_pressed_buttons();
                oled_need_refresh = true;
            }
            break;
        case STATE_PLAYING:
            handle_playback_active_inputs();

            if (btn_trigger_clicked[IDX_PLAY]) {
                btn_trigger_clicked[IDX_PLAY] = false;

                if (playback_time_valid && !play_paused) {
                    playback_base_time_ms +=
                        (millis() - playback_tag_start_system_ms);
                }

                play_paused = true;
                playback_user_paused = true;
                playback_permitted = false;
                current_state = STATE_PLAY_STANDBY;
                reset_and_ignore_pressed_buttons();
                oled_need_refresh = true;
                break;
            }

            if (btn_trigger_clicked[IDX_STOP] || btn_trigger_repeat[IDX_STOP]) {
                btn_trigger_clicked[IDX_STOP] = false;
                btn_trigger_repeat[IDX_STOP] = false;
                stop_playback_and_return_idle();
                reset_and_ignore_pressed_buttons();
                oled_need_refresh = true;
                break;
            }

            handle_sd_playback_stream();
            monitor_playback_finalize();
            break;
    }

    update_oled_display();
    delay(1);
}

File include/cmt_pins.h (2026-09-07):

#pragma once

// GPIO pin assignments
#define PICO_IN_PIN      17  // CMT input
#define PICO_OUT_PIN     19  // CMT output
#define REMOTE_PIN       18  // Remote detect input
#define BUZZER_PIN       16

#define PICO_I2C_SDA_PIN 10 // OLED I2C SDA
#define PICO_I2C_SCL_PIN 11 // OLED I2C SCL

#define PICO_SD_CS_PIN   13  // SD card SPI CS
#define PICO_SPI_MISO_PIN 12 // SD card SPI MISO(RX)
#define PICO_SPI_MOSI_PIN 15 // SD card SPI MOSI(TX)
#define PICO_SPI_CLK_PIN  14 // SD card SPI SCK
#define PICO_SPI_DETECT_PIN 9 // SD card detect input

#define BTN_REC_PIN      5
#define BTN_PLAY_PIN     4
#define BTN_STOP_PIN     6
#define BTN_OK_PIN       7
#define BTN_CANCEL_PIN   8
#define BTN_UP_PIN       1
#define BTN_DOWN_PIN     3
#define BTN_LEFT_PIN     0
#define BTN_RIGHT_PIN    2
#define NUM_BUTTONS      9

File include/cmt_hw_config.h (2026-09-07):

#pragma once

// Common hardware / behavior configuration
#define SCREEN_ADDRESS   0x3C

// Common stream and queue sizing
#define BUFFER_SIZE      512
#define SD_WRITE_TRIGGER 512
#define SD_READ_SIZE     512
#define PLAY_QUEUE_LENGTH 2048

#define DEBOUNCE_MS      20
#define LONG_PRESS_MS    1000
#define REPEAT_MS        60

#define REC_TIMEOUT_MS   10000

#define LINE_HEIGHT      16

#define MAX_DATA_PAYLOAD 32768

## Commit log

2026-09-07 1st release
    [bom.csv, parts_list.csv, picoDataRecorder.kicad_pcb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]
2026-09-09 <fix> T88/CASのマージ修正 <fix> MSXのBASICファイル名取得修正 <mod> 再生中の時間表示追加 <mod> REMOTE端子のチャタリング対応
    [cmt_ui.cpp, main.cpp]
2026-09-09 README修正
2026-09-17 [mod] P6対応
2026-10-28 [mod] T77 (FM-7) の録音・変換・再生に対応。ヘッダからファイル名を拾ってリネームに使う [mod] P6T (PC-6001) の録音・変換・再生・追記録音に対応。Rec Fmt に P6T を追加 [mod] FTP を廃止し、Webファイルマネージャ (http://picocmt.local/) を追加 [mod] 設定メニューに Web Pass (認証 ON/OFF・パ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
2026-11-03 [fix] 録音: 入力ピンの同期回路のバイパスをやめた (値が時間ごと抜けてバイトが化け、PC-8801 でロードエラーになっていた) [fix] 録音: PIO の分周比をシステムクロックから計算する (133MHz の Pico W で約6.4%長く測っていた) [mod] 録音: 受信 FIFO を8段にし、取りこぼしの回数を録音の終わりにシリアルログへ出す [fix] 再生・録音中は 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
2026-11-03 [mod] README に、PC-6001 (P6 / P6T) と FM-7 (T77) は実機・エミュレータでの動作確認をしていないことを明記
2026-11-09 [fix] 録音:1つのブロックの途中で600/1200ボーが切り替わるテープを読めなかった(長いMarkの後でボーレートを決め直し、600/1200ボーの2通りの試し読みで決める) [fix] T88の変換:前後を長いMarkに挟まれた1バイトのDATAを雑音として捨てていた [fix] T88の変換:トレーラーの終わりでモーターが止まりかけた所を、間延びした短いDATAとして残していた [f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
